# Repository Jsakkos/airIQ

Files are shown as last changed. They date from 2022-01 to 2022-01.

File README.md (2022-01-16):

# airIQ
Indoor Air quality meter that measures CO_2, particulates, VOCs, temperature, humidity, and pressure. LED indicator displays the PM2.5 AQI by color.

## Parts list

### Processor
[Wemos D1 Mini Microprocessor](https://www.ebay.com/itm/143348901029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) - $20 for 5

### CO2, temperature, and humidity sensor
[Sensirion SCD40 or SCD41](https://www.adafruit.com/product/5187) - $49.50 

### VOC sensor
[Sensirion SGP40](https://www.adafruit.com/product/4829) - $14.95 

### PM2.5 sensor
[Sensirion SPS30](https://www.sparkfun.com/products/15103) -  $46.95

### Barometric pressure sensor
[Bosch BMP280](https://www.adafruit.com/product/2651) - $9.95

### Indicator LED
[NeoPixel 5050](https://www.adafruit.com/product/1655) - $4.50 for 10

## PCB Design


[Gerber files](pcb/Gerber_PCB_AirQv2_2022-01-16.zip)

#### Inspired by:
https://www.jeffgeerling.com/blog/2021/airgradient-diy-air-quality-monitor-co2-pm25 and https://howtomechatronics.com/projects/diy-air-quality-monitor-pm2-5-co2-voc-ozone-temp-hum-arduino-meter/

## Example YAML file for ESPHome
```
esphome:
  name: kitchen-air-quality
  platform: ESP8266
  board: d1_mini
  
  on_boot:
    priority: 30
    then:
      - light.turn_on:
          id: kitchen_aqi
          effect: "Display AQI"
          brightness: 50%
# Enable logging
logger:

# Enable Home Assistant API
api:

ota:
  password: set_ota password

wifi:
  ssid: your_ssid
  password: your_wifi_password

  # Enable fallback hotspot (captive portal) in case wifi connection fails
  ap:
    ssid: "Kitchen-AQ Fallback Hotspot"
    password: ap_password

captive_portal:

i2c:
  sda: 4
  scl: 5
  scan: true
  id: bus_a
# Particle sensor
sensor:
  - platform: sps30
    pm_1_0:
      name: "Kitchen PM <1µm Weight concentration"
      id: "kitchen_PM_1_0"
    pm_2_5:
      name: "Kitchen PM <2.5µm Weight concentration"
      id: "kitchen_PM_2_5"
    pm_4_0:
      name: "Kitchen PM <4µm Weight concentration"
      id: "kitchen_PM_4_0"
    pm_10_0:
      name: "Kitchen PM <10µm Weight concentration"
      id: "kitchen_PM_10_0"
    pmc_0_5:
      name: "Kitchen PM <0.5µm Number concentration"
      id: "kitchen_PMC_0_5"
    pmc_1_0:
      name: "Kitchen PM <1µm Number concentration"
      id: "kitchen_PMC_1_0"
    pmc_2_5:
      name: "Kitchen PM <2.5µm Number concentration"
      id: "kitchen_PMC_2_5"
    pmc_4_0:
      name: "Kitchen PM <4µm Number concentration"
      id: "kitchen_PMC_4_0"
    pmc_10_0:
      name: "Kitchen PM <10µm Number concentration"
      id: "kitchen_PMC_10_0"
    pm_size:
      name: "Kitchen Typical Particle size"
      id: "kitchen_pm_size"
    address: 0x69
    update_interval: 10s
  - platform: scd4x
    co2:
      name: "Kitchen CO2"
    temperature:
      name: "Kitchen Temperature"
      id: "kitchen_temperature"
    humidity:
      name: "Kitchen Humidity"
      id: "kitchen_humidity"
    update_interval: 30s
  - platform: sgp40
    name: "Kitchen VOC"
    id: "kitchen_voc"
    update_interval: 5s
    compensation:
      humidity_source: kitchen_humidity
      temperature_source: kitchen_temperature
  - platform: bmp280
    temperature:
      name: "Kitchen Temperature 2"
      oversampling: 16x
    pressure:
      name: "Kitchen Pressure"
    address: 0x77
    update_interval: 60s

uart:
  id: uart_2
  rx_pin: D4   
  tx_pin: D3   
  baud_rate: 115200 

light:
  - platform: neopixelbus
    type: GRB
    variant: 800KBPS
    pin: GPIO3
    num_leds: 1
    name: "Kitchen AQI"
    id: kitchen_aqi
    effects:
      - lambda:
          name: "Display AQI"
          update_interval: 30s
          lambda: |-
            auto call = id(kitchen_aqi).turn_on();
            call.set_transition_length(1000);
            call.set_brightness(0.5);
            if (id(kitchen_PM_2_5).state >= 0 && id(kitchen_PM_2_5).state < 12) {
              call.set_rgb(0, 1, 0);
            } else if (id(kitchen_PM_2_5).state >= 12 && id(kitchen_PM_2_5).state < 35) {
              call.set_rgb(1, 0.93, 0);
            } else if (id(kitchen_PM_2_5).state >= 35 && id(kitchen_PM_2_5).state < 55) {
              call.set_rgb(1, 0.4, 0);
            } else if (id(kitchen_PM_2_5).state >= 55 && id(kitchen_PM_2_5).state < 150) {
              call.set_rgb(1, 0, 0);
            } else if (id(kitchen_PM_2_5).state >= 150 && id(kitchen_PM_2_5).state < 250) {
              call.set_rgb(0.85, 0, 1);
            } else if (id(kitchen_PM_2_5).state >= 250) {
              call.set_rgb(1, 0, 0.22);
            }    
            call.perform();
```

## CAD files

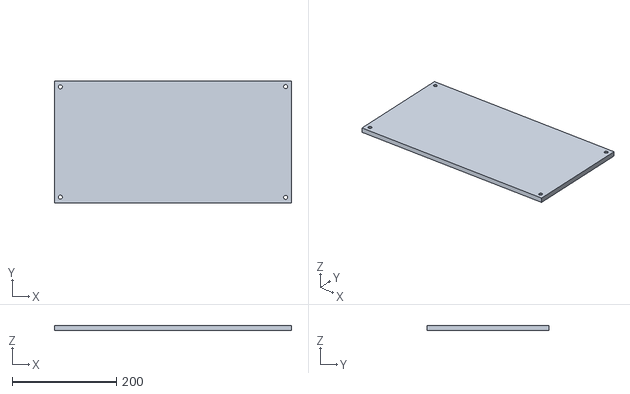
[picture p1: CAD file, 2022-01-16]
pcb/OBJ_PCB_AirQv2.obj
455.1 x 235.0 x 10.0

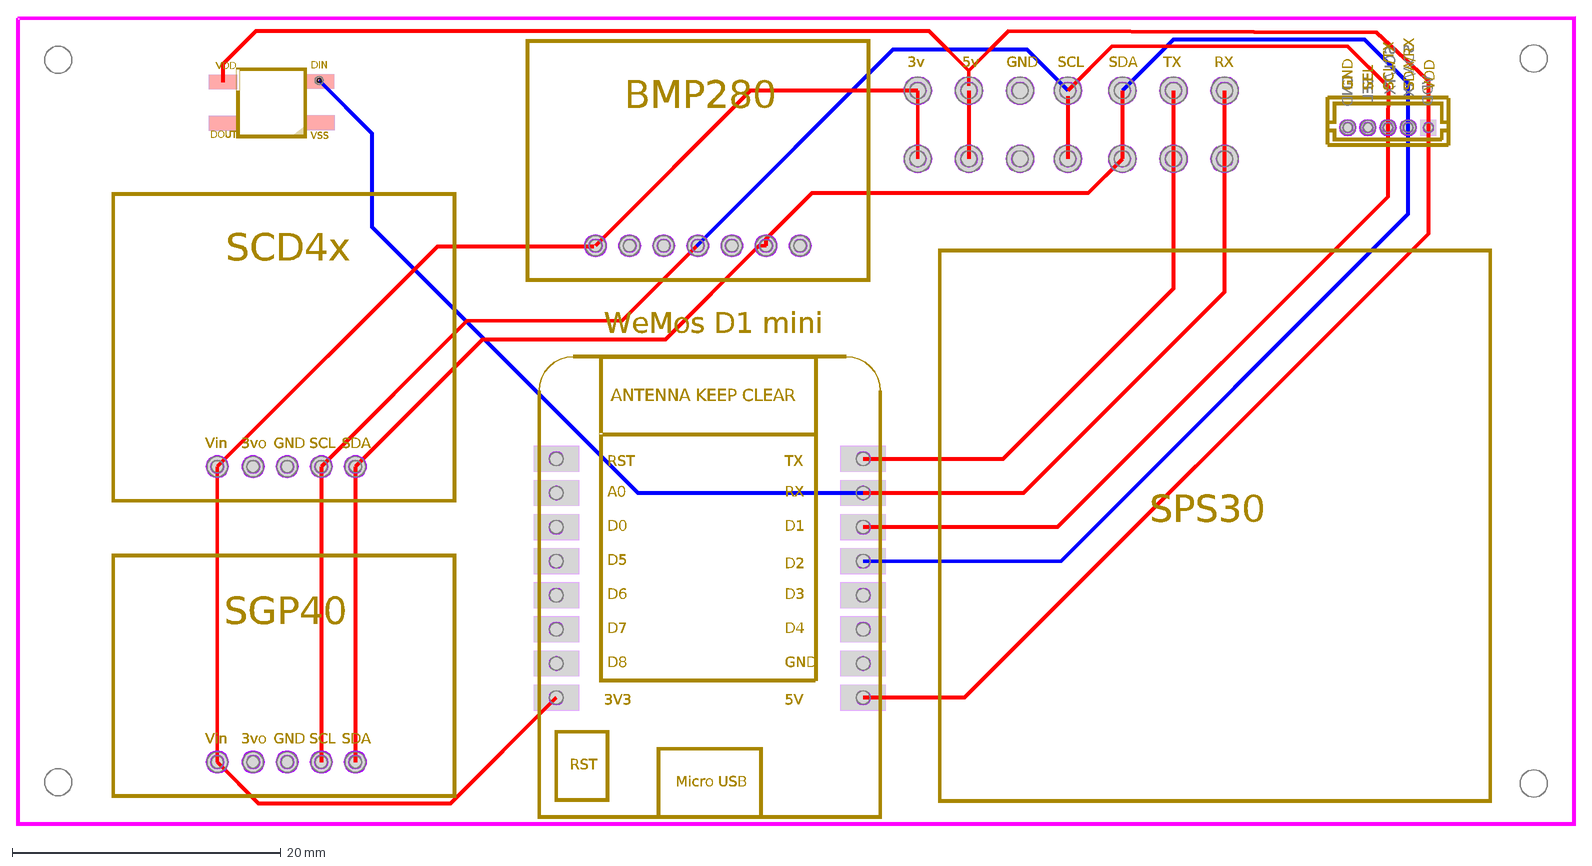
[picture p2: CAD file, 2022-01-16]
pcb/PCB_AirQv2_2022-01-16.dxf
3v
5v
GND
SCL
SDA
TX
RX
BMP280
DIN
VSS
VDD
DOUT
SCD4x
Vin
3vo
WeMos D1 mini
RST
A0
D0
D5
D6
D7
D8
3V3
5V
D4
D3
D2
D1
ANTENNA KEEP CLEAR
Micro USB
SDA/RX
SCL/TX
SEL
SPS30
SGP40
